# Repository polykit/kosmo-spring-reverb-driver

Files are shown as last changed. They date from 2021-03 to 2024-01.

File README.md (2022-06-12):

# Kosmo Spring Reverb Driver

This repository contains KiCad schematics and PCB layout for a spring reverb driver in Kosmo modular synthesizer format. It is capable to drive reverbs with an impedance from 8 to 600 ohms. There is a short video at [https://www.youtube.com/watch?v=zHZOu3KcKBQ](https://www.youtube.com/watch?v=zHZOu3KcKBQ).

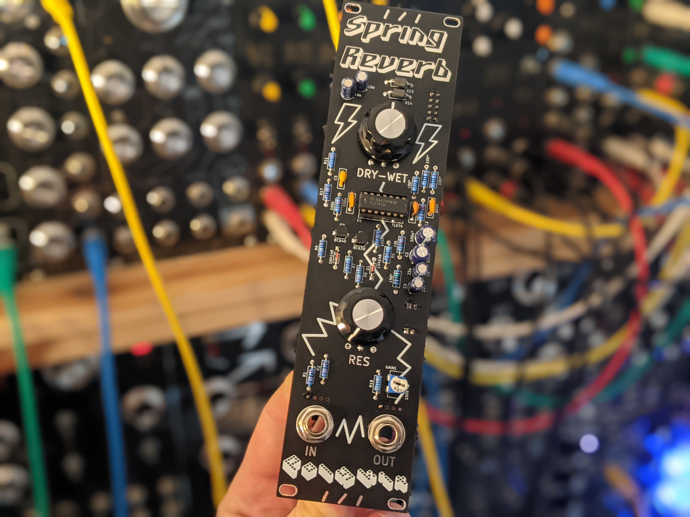
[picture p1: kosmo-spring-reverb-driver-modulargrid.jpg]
Kosmo Reverb Driver PCB


## Schematics

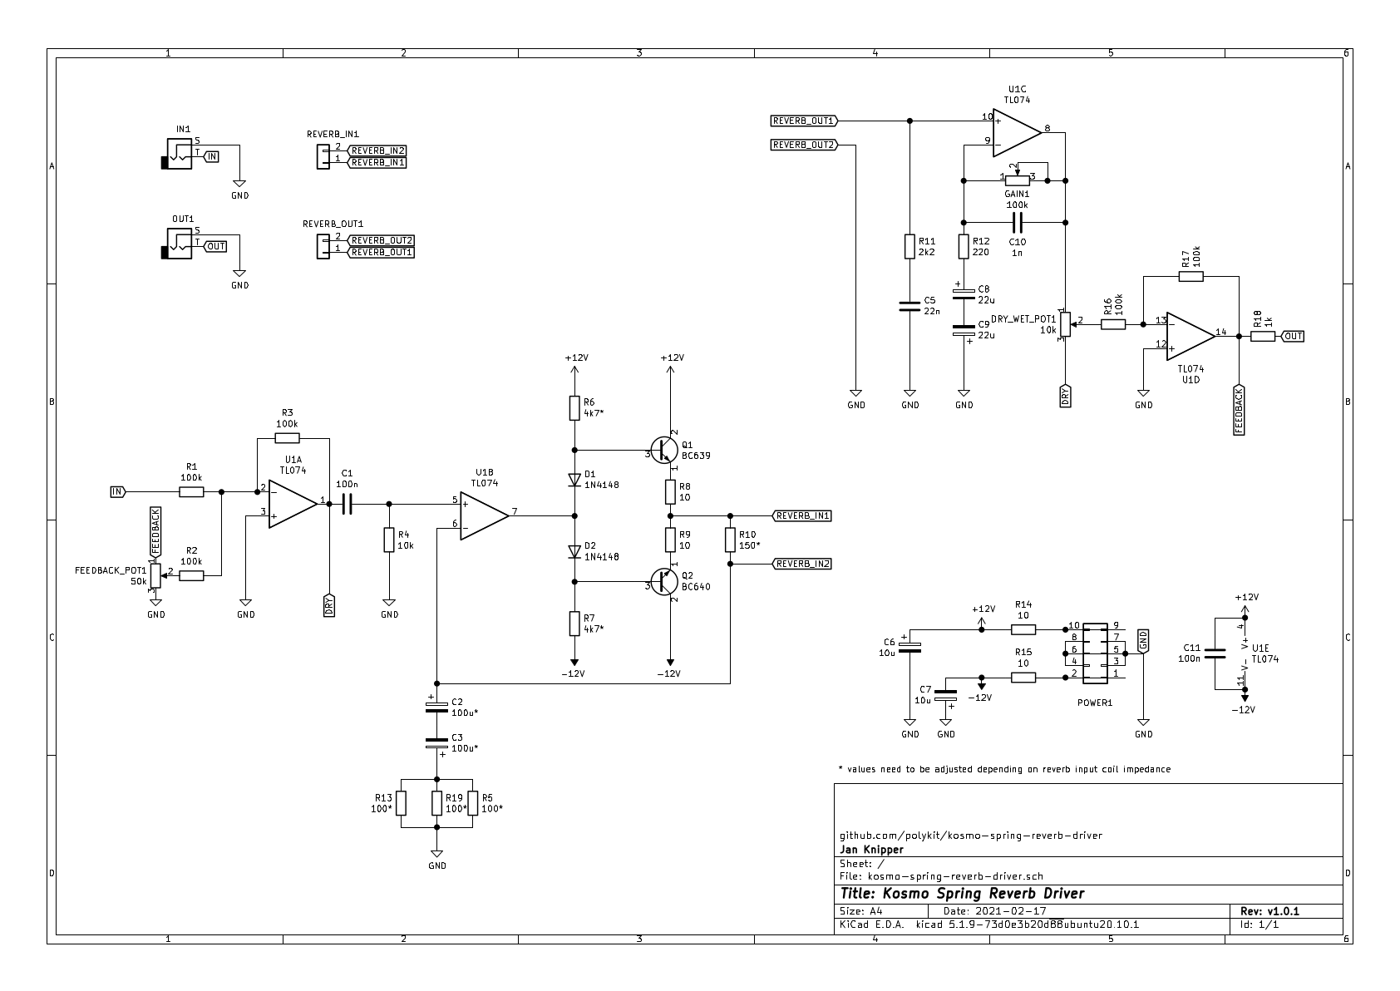
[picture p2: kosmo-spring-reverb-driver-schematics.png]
Kosmo Reverb Driver Schematics


## Building

Just put everything in, all values are marked on the PCB. Start with the lowest profile. The board is also the front panel of the module so components stick out. It is also possible to solder most of the components on the back if wanted.

*You need a separate spring reverb tank for this module. Marked component values need to be changed depending on your reverbs impedance. The values written on the board are for 8 ohm impedance. I drive an Accutronics 4AB2A1C with it. You need to make sure that the input coil is not grounded to the tanks casing or it won't work.*

### Coil impedance

| Input Coil Impedance | R5, R13, R19 | R10 | R6, R7 | C2, C3 | 
|---|---|---|---|---|
| 8R | 100R | 150R | 4k7 | 100uF  |
| 150R | 470R | 3k3 | 6k8 | 22uF |
| 200R | 560R | 3k9 | 6k8 | 22uF |
| 250R | 680R | 5k6 | 6k8 | 22uF |
| 600R | 1k | 12k | 6k8 | 22uF |

*I only tested values for 8 ohm impedance coils. You might need to fiddle around with listed values for good results.*

### BOM

|Designator|Quantity |Designation |
|---|---|---|
|C3,C2 |2 |100u* |
|R19,R13,R5|3 |100* |
|GAIN1 |1 |100k trimpot 5mm |
|R18 |1 |1k |
|REVERB_OUT1,REVERB_IN1|2 |2 pin connector |
|C9,C8 |2 |22u |
|C7,C6 |2 |10u |
|POWER1 |1 |IDC 10 pin male connector |
|C11,C1 |2 |100n |
|C10 |1 |1n |
|C5 |1 |22n |
|OUT1,IN1  |2 |Audio Jack 6,35mm |
|FEEDBACK_POT1|1 |50k pot |
|DRY_WET_POT1|1 |10k pot |
|U1 |1 |TL074 |
|R17,R16,R3,R2,R1|5 |100k |
|R15,R14,R9,R8|4 |10 |
|R12 |1 |220 |
|R11 |1 |2k2 |
|R10 |1 |150* |
|R7,R6 |2 |4k7* |
|R4 |1 |10k |
|Q2 |1 |BC640 |
|Q1 |1 |BC639 |
|D2,D1 |2 |1N4148 |

## References

https://sound-au.com/articles/reverb.htm

https://kassu2000.blogspot.com/2015/10/spring-reverb.html

https://www.lookmumnocomputer.com/modular

https://github.com/telec16/kicad

https://github.com/holmesrichards/Kosmo_panel

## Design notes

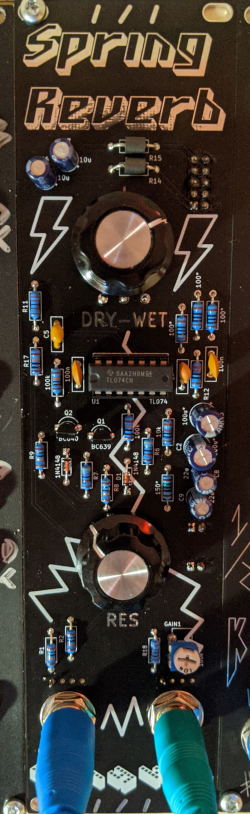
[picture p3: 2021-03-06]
kosmo-spring-reverb-driver-pcb.png

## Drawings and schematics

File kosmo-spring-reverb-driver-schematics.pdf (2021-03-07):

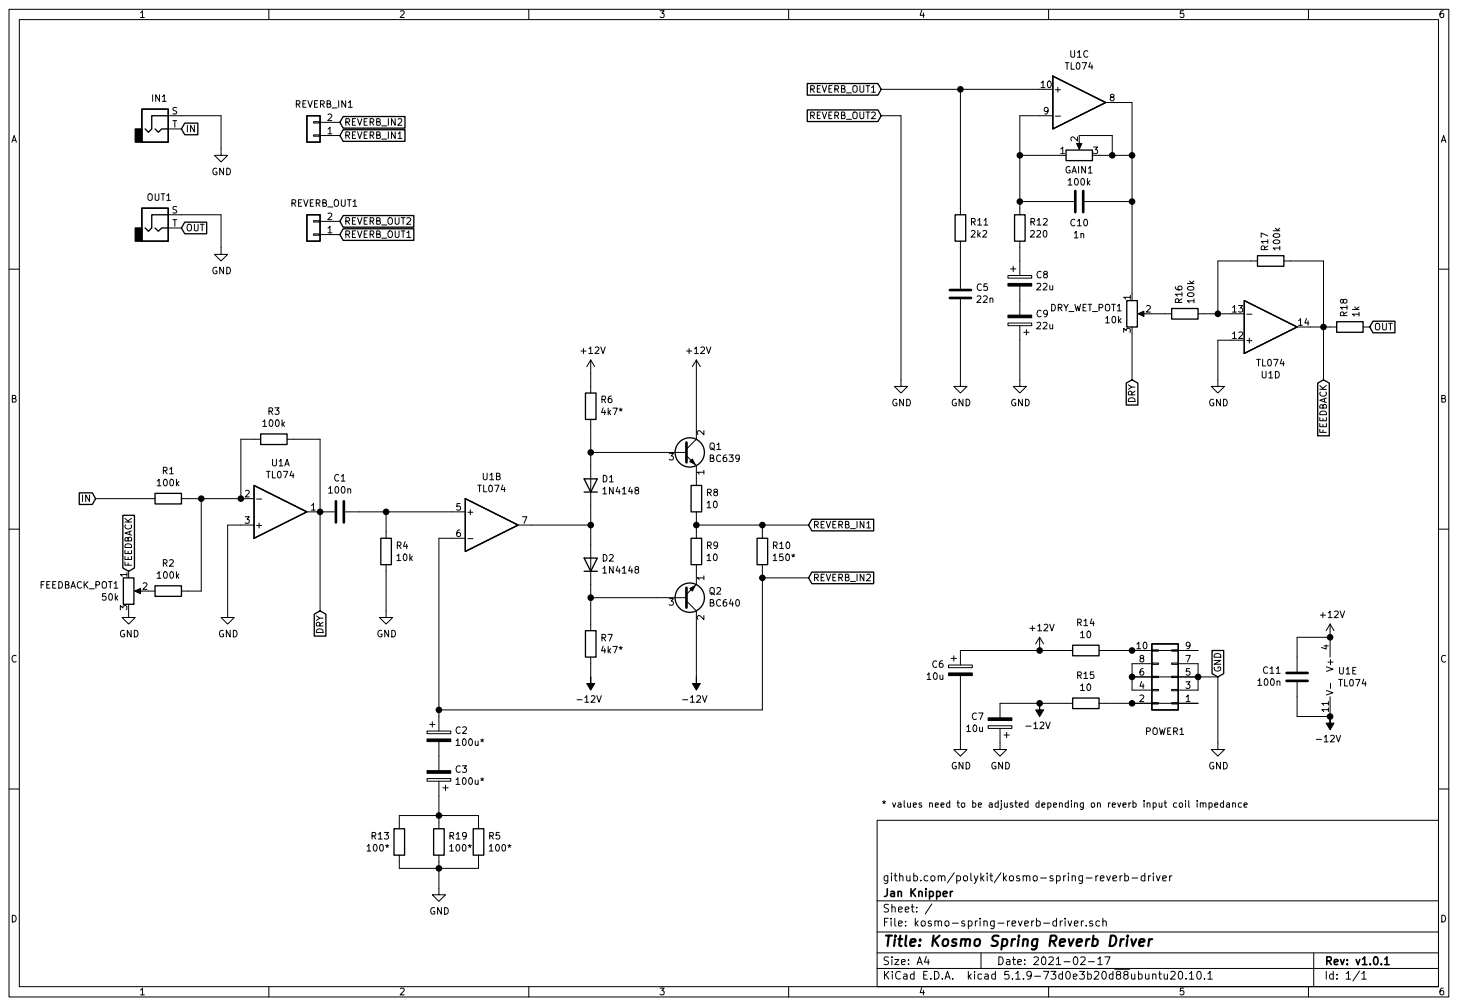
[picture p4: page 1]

github.com/polykit/kosmo-spring-reverb-driver GND

* values need to be adjusted depending on reverb input coil impedance

File: kosmo-spring-reverb-driver.sch Sheet: / Jan Knipper

Id: 1/1 Title: Kosmo Spring Reverb Driver

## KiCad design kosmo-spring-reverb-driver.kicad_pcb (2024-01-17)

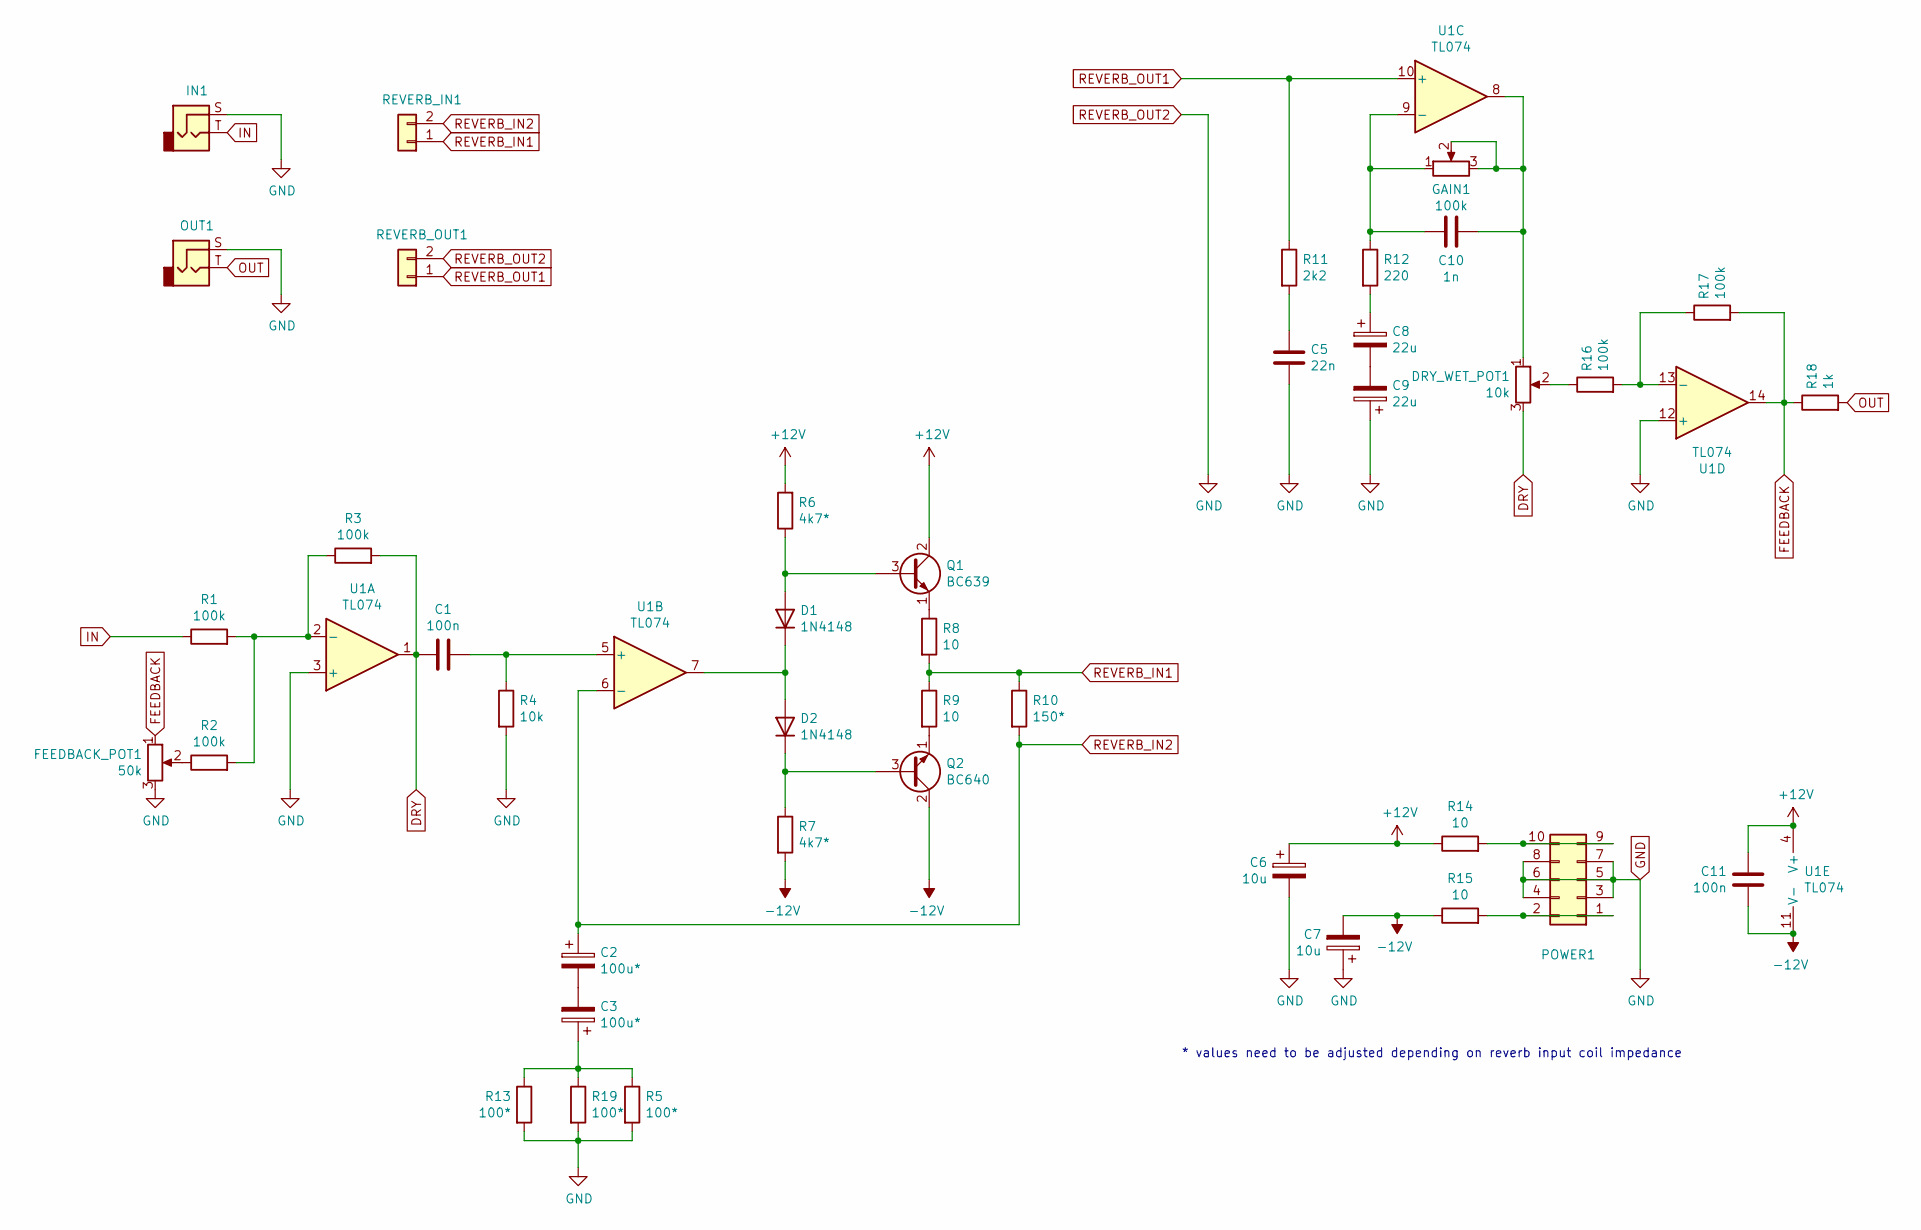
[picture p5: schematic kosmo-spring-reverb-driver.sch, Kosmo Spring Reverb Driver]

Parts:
C1, C11: 100n; C_Disc_D8.0mm_W2.5mm_P5.00mm
C2, C3: 100u*; CP_Radial_D6.3mm_P2.50mm
C5: 22n; C_Disc_D8.0mm_W2.5mm_P5.00mm
C6, C7: 10u; CP_Radial_D5.0mm_P2.50mm
C8, C9: 22u; CP_Radial_D5.0mm_P2.50mm
C10: 1n; C_Disc_D8.0mm_W2.5mm_P5.00mm
D1, D2: 1N4148; D_DO-35_SOD27_P7.62mm_Horizontal
DRY_WET_POT1: 10k; Potentiometer_Single_Vertical_Hole
FEEDBACK_POT1: 50k; Potentiometer_Single_Vertical_Hole
GAIN1: 100k; Potentiometer_ACP_CA9-H5_Horizontal
IN1: AudioJack2; Jack_Hole_Square
OUT1: AudioJack2; Jack_Hole_Square
POWER1: Conn_02x05_Odd_Even; IDC-Header_2x05_P2.54mm_Vertical
Q1: BC639; TO-92_Inline_Wide
Q2: BC640; TO-92_Inline_Wide
R1, R2, R3, R16, R17: 100k; R_Axial_DIN0207_L6.3mm_D2.5mm_P10.16mm_Horizontal
R4: 10k; R_Axial_DIN0207_L6.3mm_D2.5mm_P10.16mm_Horizontal
R5, R13, R19: 100*; R_Axial_DIN0207_L6.3mm_D2.5mm_P10.16mm_Horizontal
R6, R7: 4k7*; R_Axial_DIN0207_L6.3mm_D2.5mm_P10.16mm_Horizontal
R8, R9, R14, R15: 10; R_Axial_DIN0207_L6.3mm_D2.5mm_P10.16mm_Horizontal
R10: 150*; R_Axial_DIN0207_L6.3mm_D2.5mm_P10.16mm_Horizontal
R11: 2k2; R_Axial_DIN0207_L6.3mm_D2.5mm_P10.16mm_Horizontal
R12: 220; R_Axial_DIN0207_L6.3mm_D2.5mm_P10.16mm_Horizontal
R18: 1k; R_Axial_DIN0207_L6.3mm_D2.5mm_P10.16mm_Horizontal
REVERB_IN1: Conn_01x02; Molex_KK-254_AE-6410-02A_1x02_P2.54mm_Vertical
REVERB_OUT1: Conn_01x02; Molex_KK-254_AE-6410-02A_1x02_P2.54mm_Vertical
U1: TL074; DIP-14_W7.62mm_Socket_LongPads

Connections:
+12V: C6.1, C11.2, Q1.2 (C), R6.2, R14.1, U1.4 (V+)
-12V: C7.2, C11.1, Q2.2 (C), R7.2, R15.1, U1.11 (V-)
DRY: C1.1, DRY_WET_POT1.3, R3.2, U1.1
FEEDBACK: FEEDBACK_POT1.1, R17.2, R18.1, U1.14
GND: C5.1, C6.2, C7.1, C9.1, FEEDBACK_POT1.3, IN1.S, OUT1.S, POWER1.3, POWER1.4, POWER1.5, POWER1.6, POWER1.7, POWER1.8, R4.2, R5.2, R13.2, R19.2, REVERB_OUT1.2, U1.3 (+), U1.12 (+)
IN: IN1.T, R1.1
unnamed: C1.2, R4.1, U1.5 (+)
unnamed: C2.2, C3.2
unnamed: C3.1, R5.1, R13.1, R19.1
unnamed: C5.2, R11.2
unnamed: C8.1, R12.2
unnamed: C8.2, C9.2
unnamed: C10.1, DRY_WET_POT1.1, GAIN1.2, GAIN1.3, U1.8
unnamed: C10.2, GAIN1.1, R12.1, U1.9 (-)
unnamed: D1.1 (K), D2.2 (A), U1.7
unnamed: D1.2 (A), Q1.3 (B), R6.1
unnamed: D2.1 (K), Q2.3 (B), R7.1
unnamed: DRY_WET_POT1.2, R16.1
unnamed: FEEDBACK_POT1.2, R2.1
unnamed: POWER1.1, POWER1.2, R15.2
unnamed: POWER1.9, POWER1.10, R14.2
unnamed: Q1.1 (E), R8.1
unnamed: Q2.1 (E), R9.2
unnamed: R1.2, R2.2, R3.1, U1.2 (-)
unnamed: R16.2, R17.1, U1.13 (-)
OUT: OUT1.T, R18.2
REVERB_IN1: R8.2, R9.1, R10.1, REVERB_IN1.1
REVERB_IN2: C2.1, R10.2, REVERB_IN1.2, U1.6 (-)
REVERB_OUT1: R11.1, REVERB_OUT1.1, U1.10 (+)

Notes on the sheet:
* values need to be adjusted depending on reverb input coil impedance

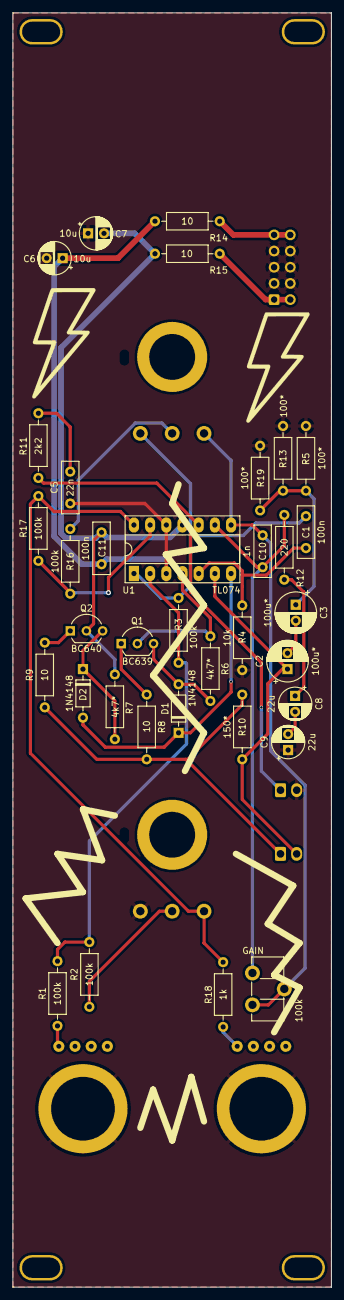
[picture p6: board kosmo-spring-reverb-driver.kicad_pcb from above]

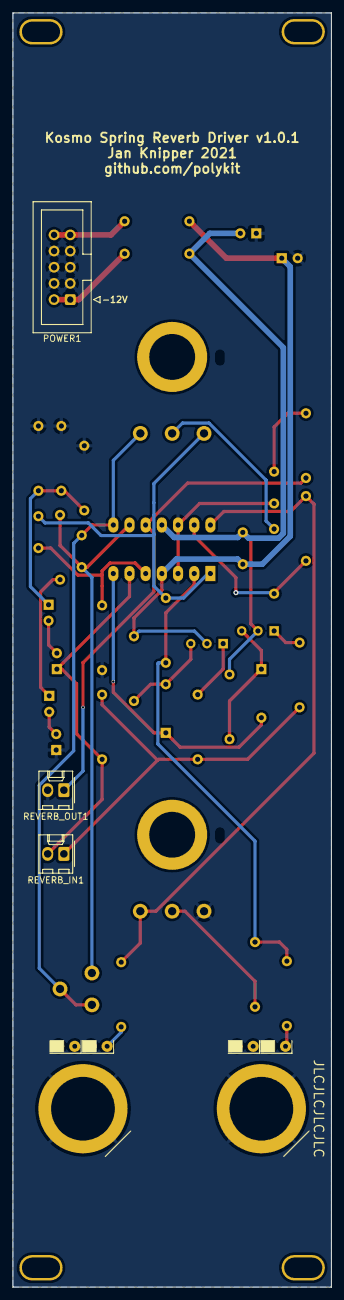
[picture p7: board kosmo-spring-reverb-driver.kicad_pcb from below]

Board: 2 copper layers, 50.0 x 200.0 mm, 42 parts (3 on the bottom side), 29 nets.

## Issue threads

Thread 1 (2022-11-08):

Question regarding the parts which depend on coil impedance

stmllr, 2022-11-08:
Thanks for publishing your gerber files. They work like a charm, a pleasure to solder.

I have some questions about the [parts, which depend on the coil input impedance](https://github.com/polykit/kosmo-spring-reverb-driverREADME.md#coil-impedance).

* Which role do the they play in the schematics? Trying to understand the logic in there.
* Which effects on the sound do you expect when changing their particular values?
* What do you mean with "good result"?

I am currently assembling two PCBs for spring tanks 8BB2C1B and 9BB2C1B, both with 150ohm impedance.
I have successfully finished one and used the values for R5/R13/R19, R10, R6, R7, C2, C3 you proposed in the README.

polykit, 2022-11-09:
Hi @stmllr, the lower the input coils impedance the higher is the needed current to drive it. This is reflected by the changed resistor values. It is needed to drive the coil at an optimal point and get the best reverberation out of it. I choose this design because it can drive tanks with a high current demand. Also take a look at the references linked in the repository.

Closed 2024-01-17.

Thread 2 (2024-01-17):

Gerber files seem to have plots offset

bastenhoor, 2024-01-17:
Hi, When uploading the plots folder to JLCPCB the drillholes seem te be offset.

polykit, 2024-01-17:
Hi @bastenhoor thanks for letting me know. I uploaded new gerber files, please give it another try.

bastenhoor, 2024-01-17:
Perfect! ;-)
Do you have the gerbers for the Eurorack version too perhaps? ;-)

polykit, 2024-01-17:
> Perfect! ;-) Do you have the gerbers for the Eurorack version too perhaps? ;-)

No, sorry, only Kosmo as of now.

bastenhoor, 2024-01-17:
No problem!

bastenhoor, 2024-01-17:
One more question: do you have a link to the audio jacks? Mouser, AliExpress, whatever. Thanks!

polykit, 2024-01-19:
> One more question: do you have a link to the audio jacks? Mouser, AliExpress, whatever. Thanks!

Any 6.35mm audio jack should do. I'm using https://www.aliexpress.com/item/32841081749.html

Closed 2024-01-17.

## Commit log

2021-03-06 Initial import
    [kosmo-spring-reverb-driver-B_Cu.gbr, kosmo-spring-reverb-driver-B_Mask.gbr, kosmo-spring-reverb-driver-B_SilkS.gbr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]
2021-03-06 Added footprint libraries
2021-03-07 Fix pot hole size, cap position
    [kosmo-spring-reverb-driver-B_Cu.gbr, kosmo-spring-reverb-driver-B_Mask.gbr, kosmo-spring-reverb-driver-B_SilkS.gbr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]
2024-01-17 Redo gerber files
    [kosmo-spring-reverb-driver-B_Cu.gbr, kosmo-spring-reverb-driver-B_Mask.gbr, kosmo-spring-reverb-driver-B_SilkS.gbr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]
